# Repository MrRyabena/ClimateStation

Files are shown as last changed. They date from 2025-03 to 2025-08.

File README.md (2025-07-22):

ClimateStation_logo

---

[](https://github.com/MrRyabena/SmartHomeSystem)


---

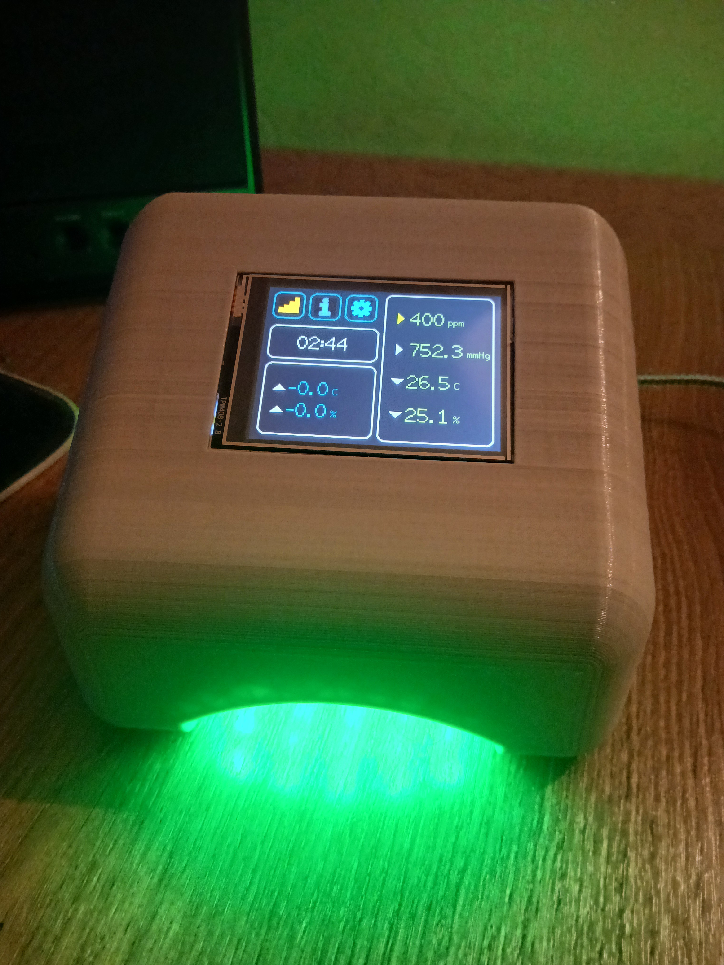
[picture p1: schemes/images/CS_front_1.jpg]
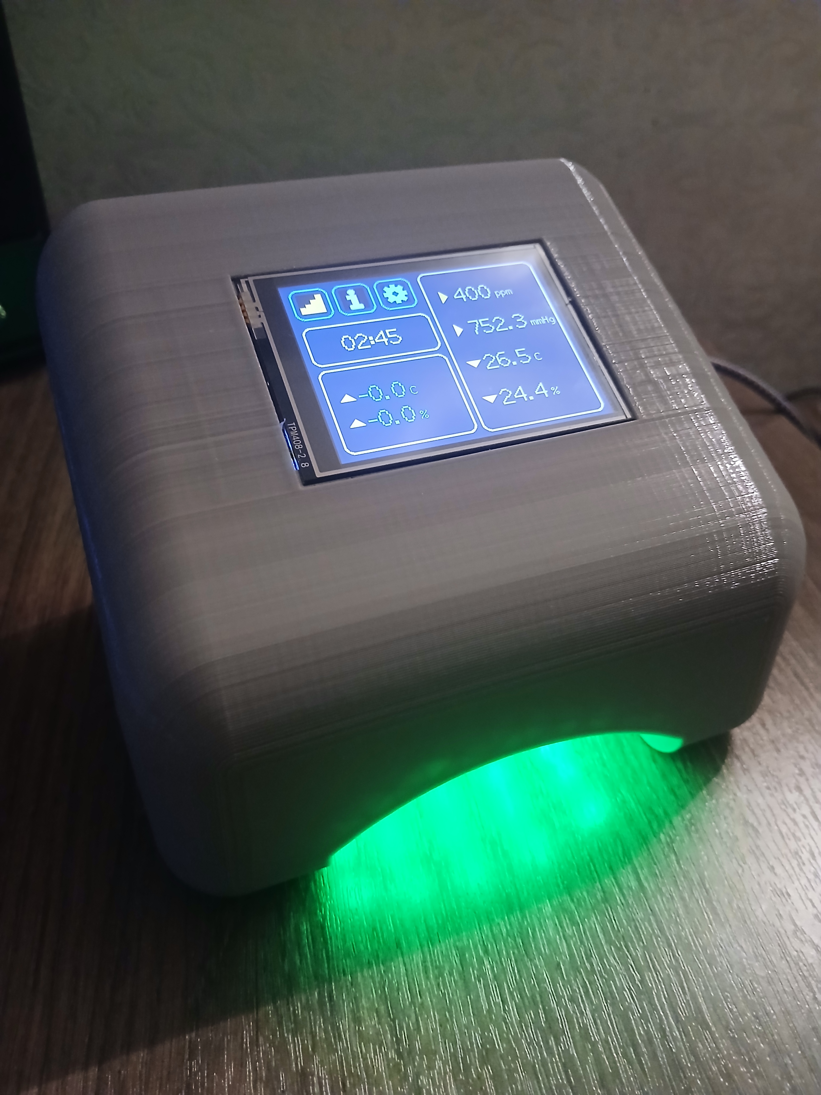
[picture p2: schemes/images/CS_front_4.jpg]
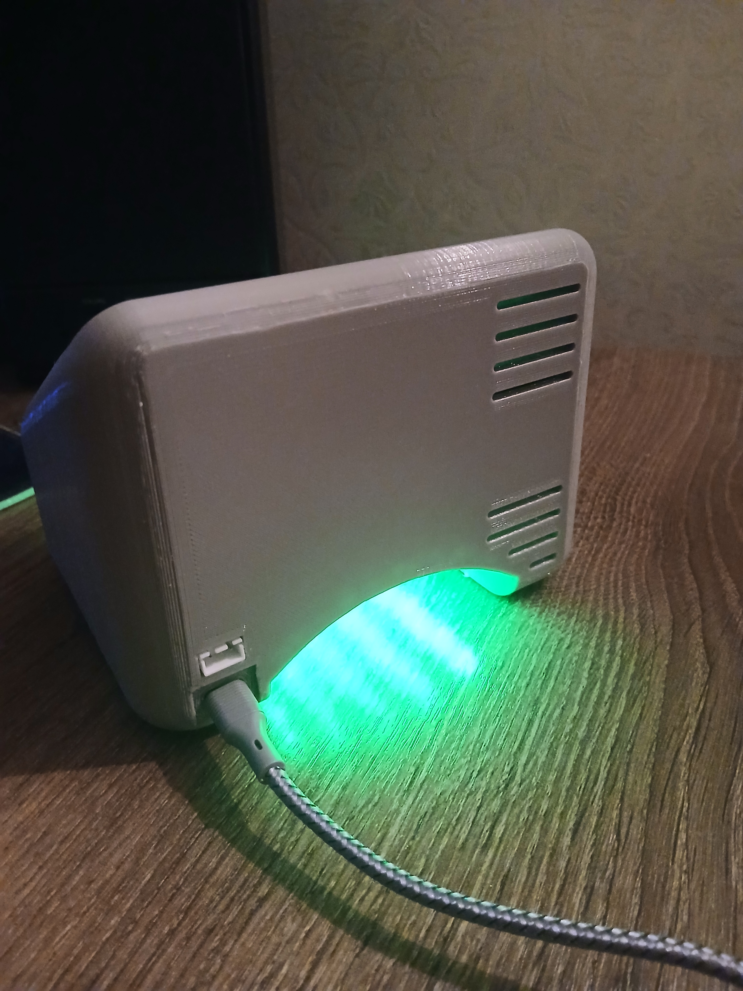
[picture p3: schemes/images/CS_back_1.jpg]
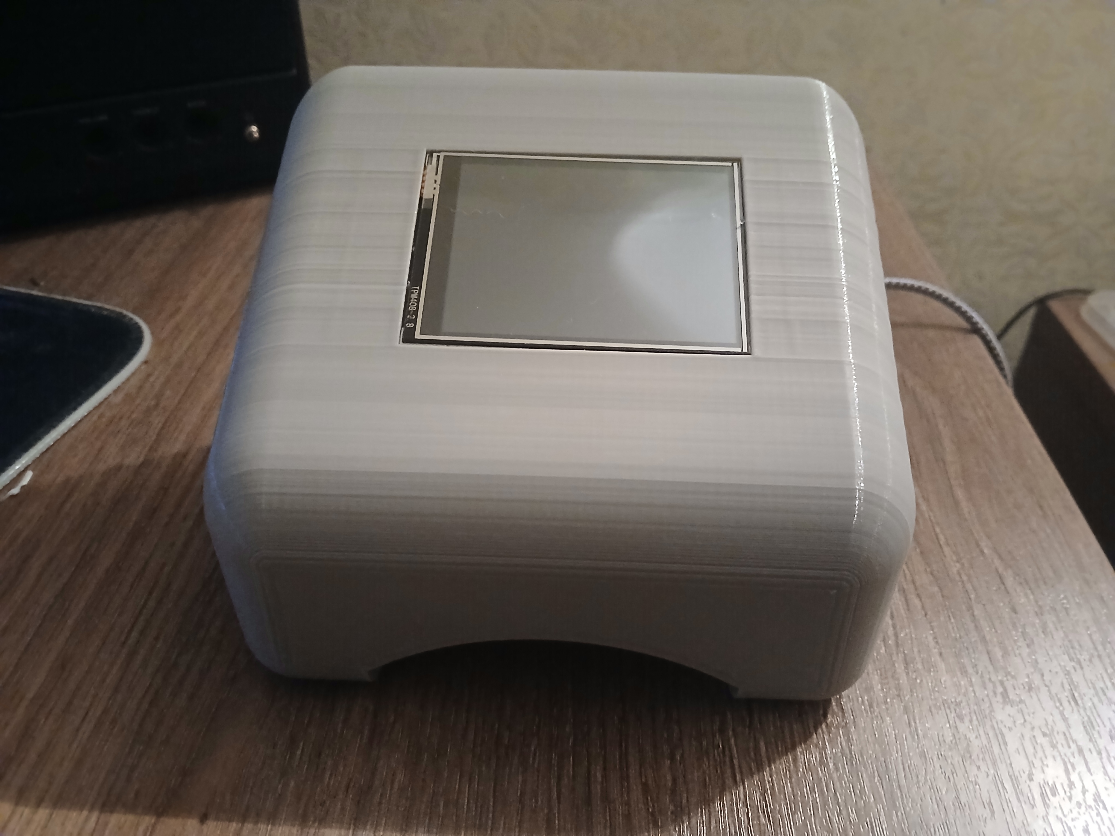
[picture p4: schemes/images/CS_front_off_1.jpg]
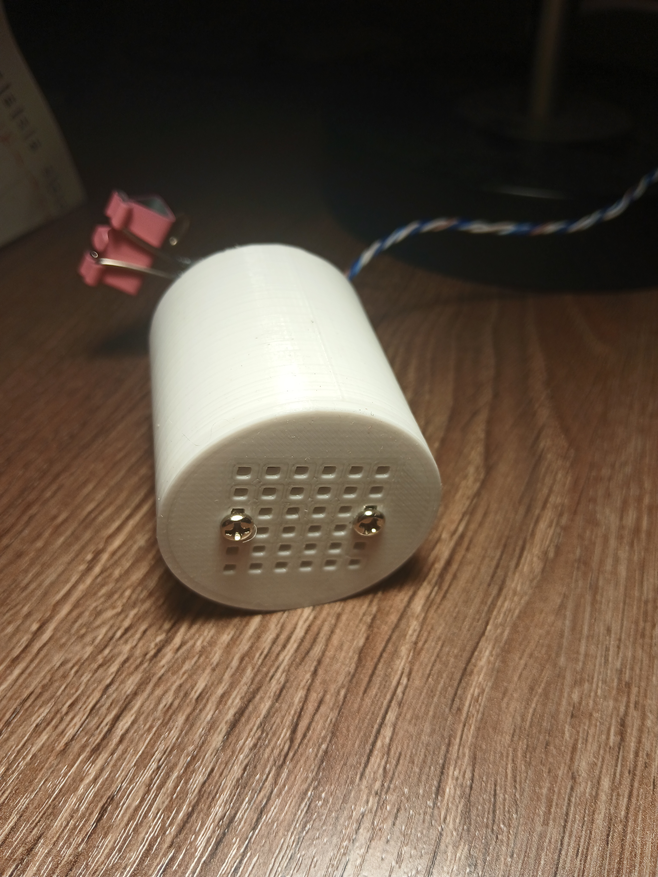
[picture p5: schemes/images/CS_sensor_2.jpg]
    

---

# ClimateStation by SmartHomeSystem

> [!NOTE]
> Проект является одним из устройств SmartHomeSystem. Внутри кода используется ядро и библиотека основного проекта — **_[SmartHomeSystem](https://github.com/MrRyabena/SmartHomeSystem)_**.</br>

## Versions

<details>
<summary>v1.0.0 — development beta-version.</summary>

</details>

<details>
<summary>v1.1.0 — <b><code>[current]</code></b>

</details>

## Components

[See list of components](/schemes/components/components_list.md).

## About

**_ClimateStation_** — метеостанция в специально разработанном для 3D-печати корпусе с сенсорным дисплеем. Собирает информацию с внутренних и внешних датчиков об атмосферном давлении, уровне CO2 (углекислого газа) в помещении, влажности и температуре воздуха. Станция умеет составлять прогноз погоды, подсказывать когда необходимо проветрить помещение и выводить показания с датчиков и графики их изменений. Сенсорный экран позволяет изменять настройки, переключать режимы работы и смотреть показания датчиков в реальном времени. Также устройство может обеспечивать обратную связь в системах климат-контроля **_SmartHomeSystem_**.

### Возможности

- Измерения:
  - Temperature in/out
  - Humidity in/out
  - Pressure
  - CO2 concentration
- Сенсорный дисплей:
  - Визуализация показателей в реальном времени
  - Расчёт и отображение тренда изменения величины (возрастает/убывает/не изменяется)
  - Переключение режимов и управление настройками
- Подсветка:
  - Визуальный контроль качества воздуха или изменения погодных условий
- Сбор и сохранение статистики
  - Вывод графиков за выбранные промежутки времени

## PCB
Для сборки устройства разработана печатная палата.





## Упаковка

Картонная [коробка](https://www.ozon.ru/product/kartonnaya-korobka-20h12h12-sm-korobka-dlya-upakovki-bizhuterii-i-yuvelirnyh-izdeliy-gofrokorob-384109582/) 200x12x12 mm. Обклеивается символикой из [logos/source/print.docx](logos/source/print.docx).

Внутрь вставляется картонная вставка (для создания разделов):

- Размеры вставки: 105x480
- Загибы: 195 + 115 + 55 + 115

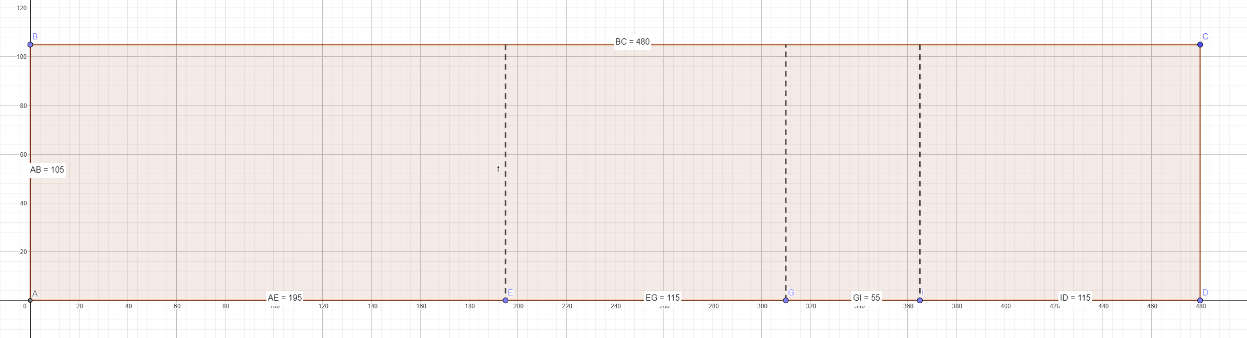
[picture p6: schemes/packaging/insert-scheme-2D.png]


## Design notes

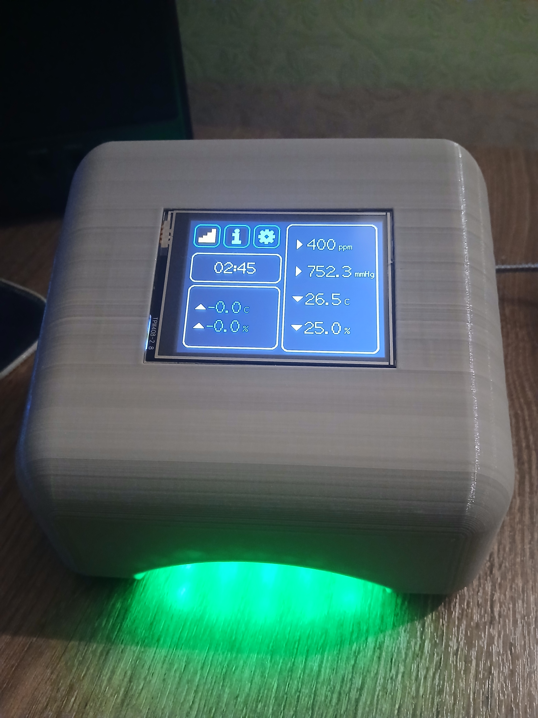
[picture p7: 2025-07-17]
schemes/images/CS_front_3.jpg

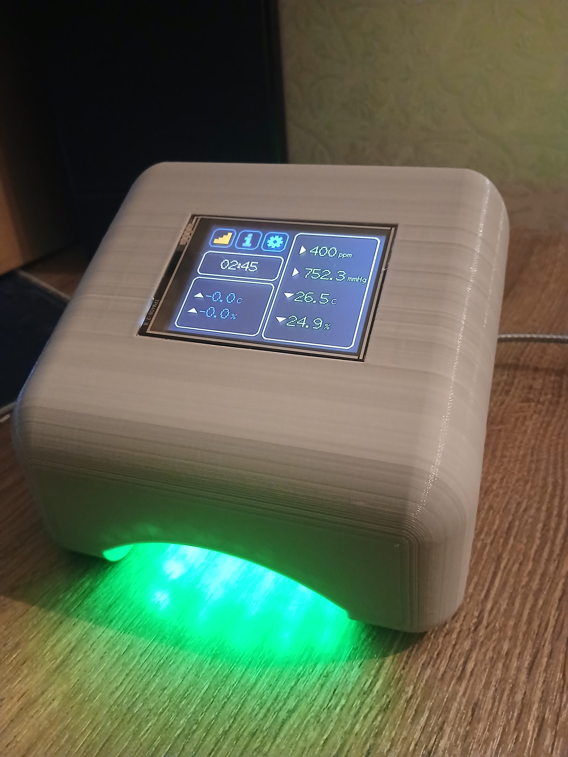
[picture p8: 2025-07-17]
schemes/images/CS_front_2.jpg

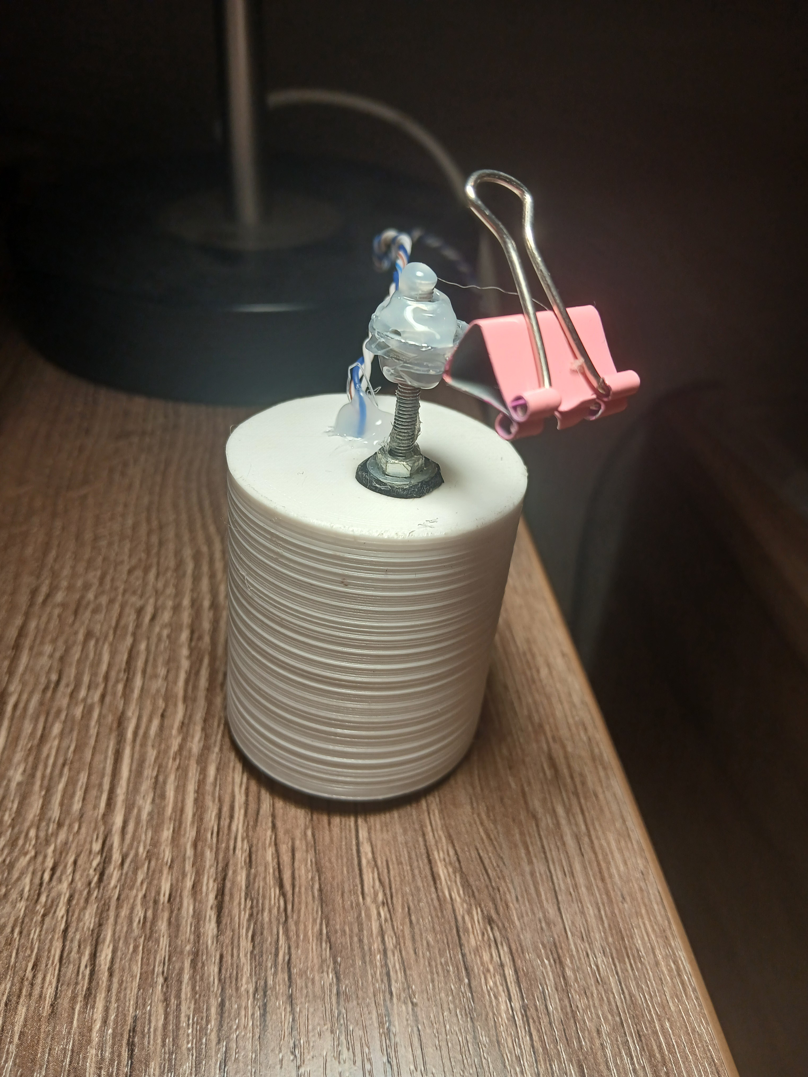
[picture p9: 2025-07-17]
schemes/images/CS_sensor_1.jpg

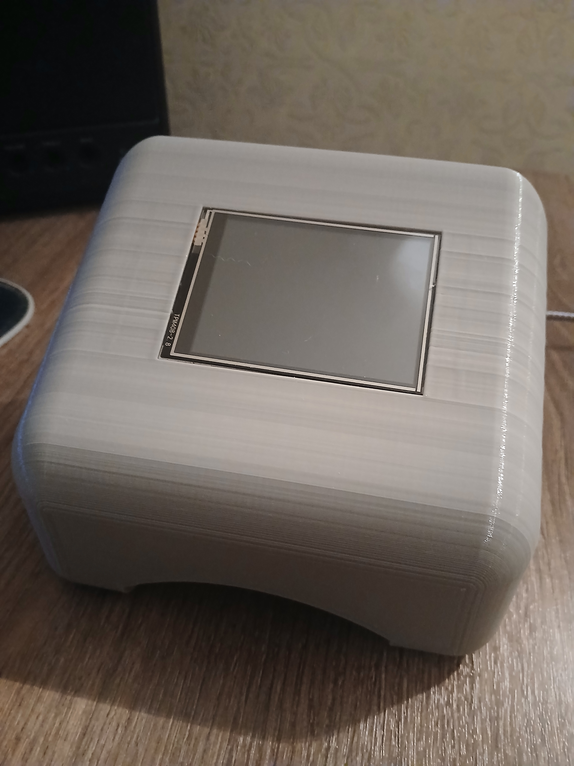
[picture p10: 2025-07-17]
schemes/images/CS_front_off_2.jpg

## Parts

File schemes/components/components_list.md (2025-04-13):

# Components

|№|component|type|datasheet|link|size|note|
|--|--|--|--|--|--|--|
|1.|MH-Z19B|sensor|[mh-z19b-co2-ver1_0.pdf](https://www.winsen-sensor.com/d/files/infrared-gas-sensor/mh-z19b-co2-ver1_0.pdf)|[Ozon](https://www.ozon.ru/search/?text=MH-Z19b&from_global=true)|33x20x9|CO2 gas sensor|
|2.|BME-280|sensor|[BME280.pdf](https://download.mikroe.com/documents/datasheets/)|[Aliexpress](https://aliexpress.ru/item/1005001827151118.html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)|16x12x2 + d3|Pressure, humidity and temperature sensor|
|3.|DTH-22|sensor|[DHT22.pdf](https://iarduino.ru/lib/DHT22.pdf?ysclid=m8ddeefn6p891731623)|[Aliexpress](https://aliexpress.ru/item/1005008495880246.html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)|34x16x8|Outdoor temperature and humidity sensor|
|4.|DS3231|clock|[ds3231.pdf](https://dinistor.ru/files/ds3231.pdf?ysclid=m8ddi9gb17518707617)|[Aliexpress](https://aliexpress.ru/item/1005007143842437.html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)|14x14x8|Real time clock module|
|5.|ESP8266/ESP32|microcontroller|—|—|—|Main controller|
|6.|3.3V dc-dc|power|—|[Aliexpress](https://aliexpress.ru/item/1005002921104409.html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)|17,5x12x5|Voltage converter|
|7.|TFT-display|display||[Aliexpress](https://aliexpress.ru/item/4000219159401.html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)|[TFT_2.8_scheme](TFT_2.8_scheme.png)|Touch display 2.8''|
|8.|usb type c|socket|—|[Aliexpress](https://aliexpress.ru/item/1005006047462864.html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)|12x15x4 + 16x12|Usp-socket for power supply|
|9.|Buzzer|buzzer|—|—|—|Buzzer|
|10.|ARGB led|LED|—|—|10x17 (1 segment)|Illumination of the lower part|
|11.|Outdoor sensor connector|connector|—|[Ozon](https://www.ozon.ru/product/razemy-3pin-shag-2-54mm-shteker-na-platu-gnezdo-na-provode-300mm-2-komplekta-1553830306/)|6x10x7 + (pins) 3(len)x2.5(step)x0.56(thin of each)|Connector for outdoor sensor (DHT22)|

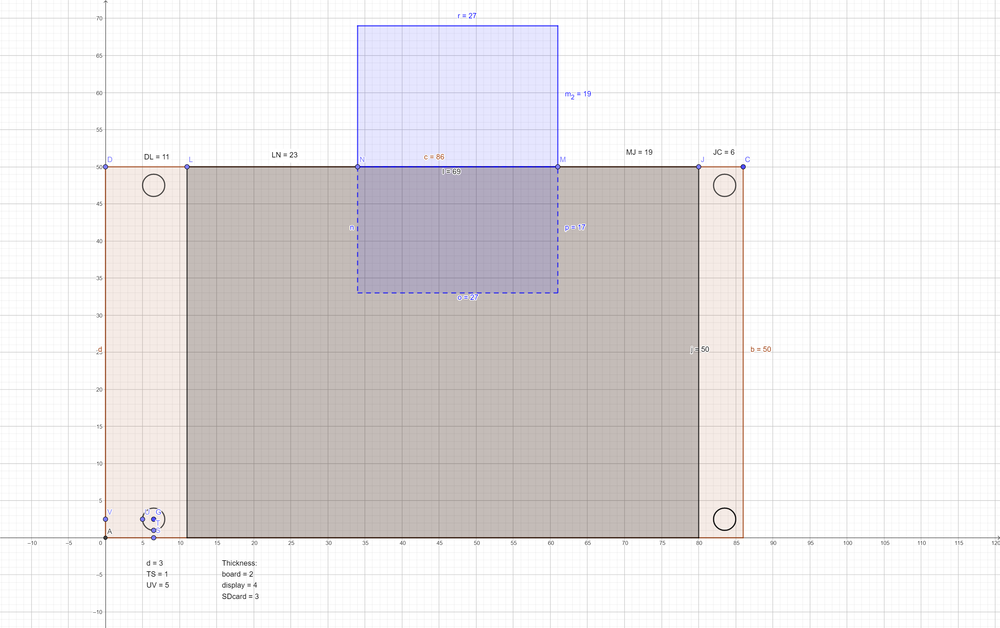
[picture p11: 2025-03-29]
schemes/components/TFT_2.8_scheme.png

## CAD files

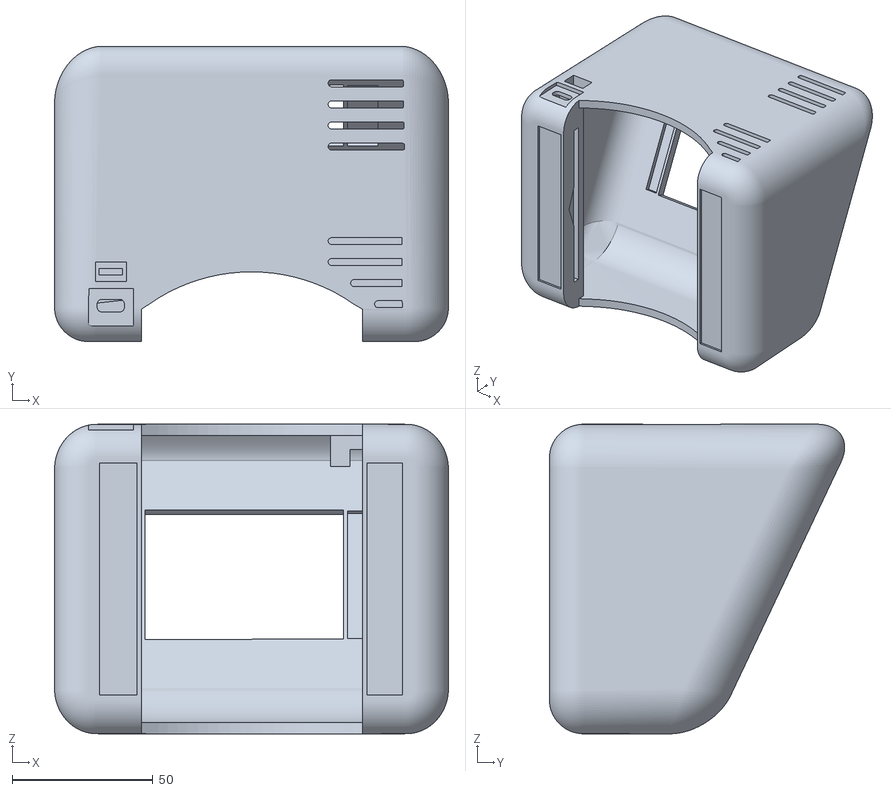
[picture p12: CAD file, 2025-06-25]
schemes/3D_models/base/base.obj
140.0 x 104.9 x 110.0

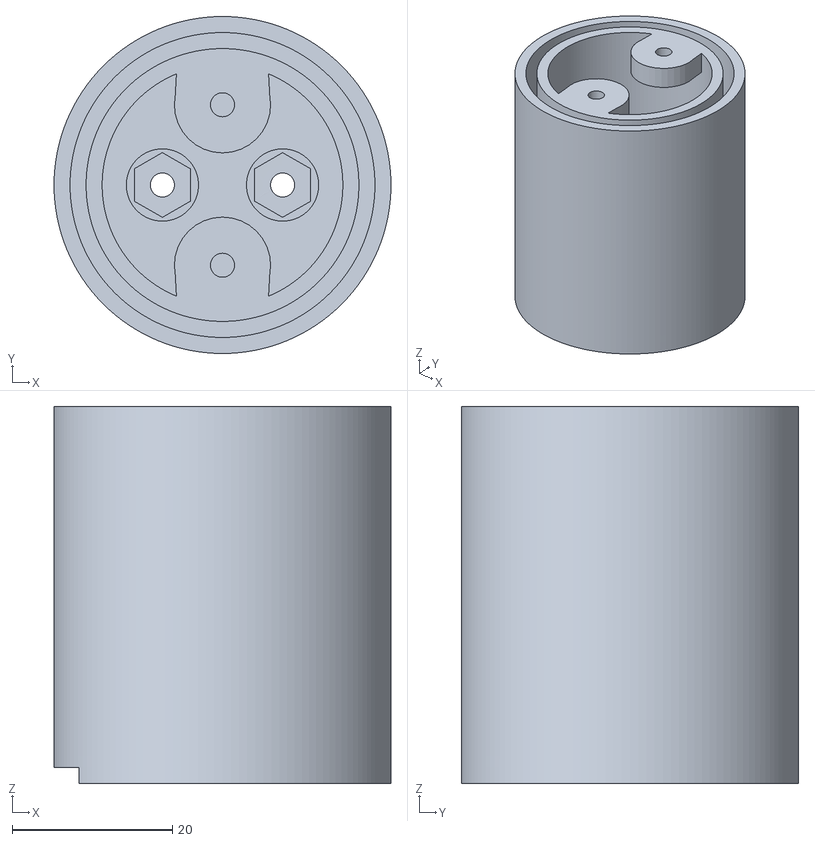
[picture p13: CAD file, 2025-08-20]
schemes/3D_models/outdoors/outdors.stl
42.0 x 42.0 x 47.0

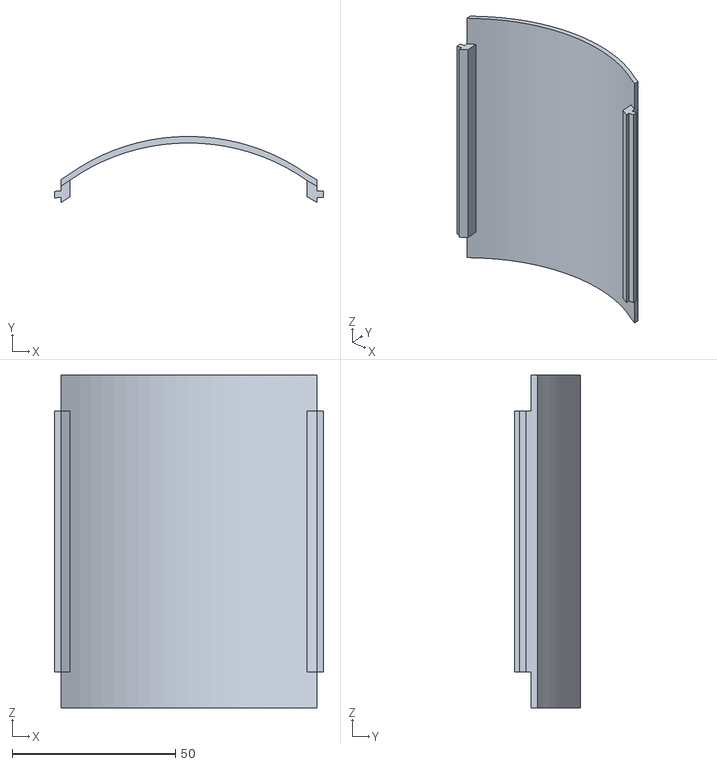
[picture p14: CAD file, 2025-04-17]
schemes/3D_models/base/cap.obj
82.5 x 20.3 x 102.0

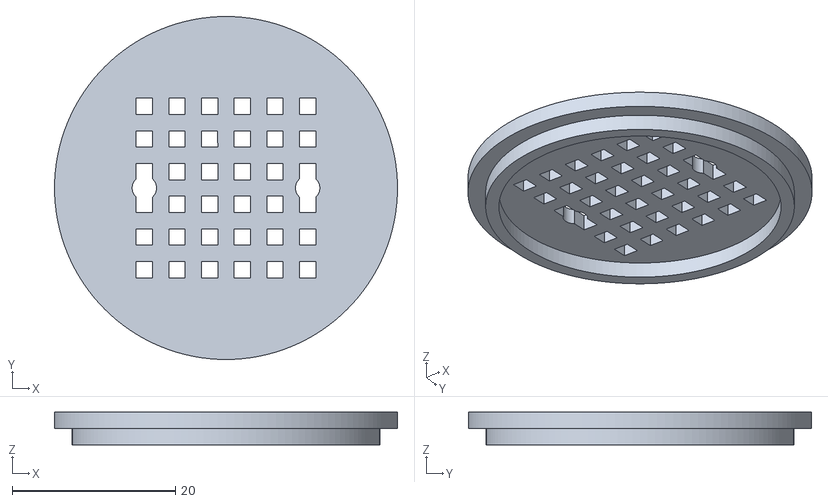
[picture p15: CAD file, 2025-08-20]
schemes/3D_models/outdoors/cap.stl
42.0 x 42.0 x 4.00

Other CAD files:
schemes/3D_models/base/cup.obj
schemes/3D_models/base/base.blend
schemes/3D_models/outdoors/cap.obj
schemes/3D_models/outdoors/outdors.blend
schemes/3D_models/outdoors/outdors.obj

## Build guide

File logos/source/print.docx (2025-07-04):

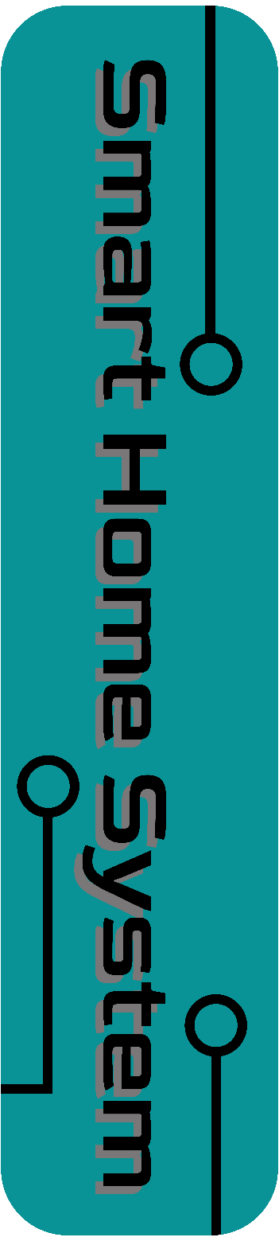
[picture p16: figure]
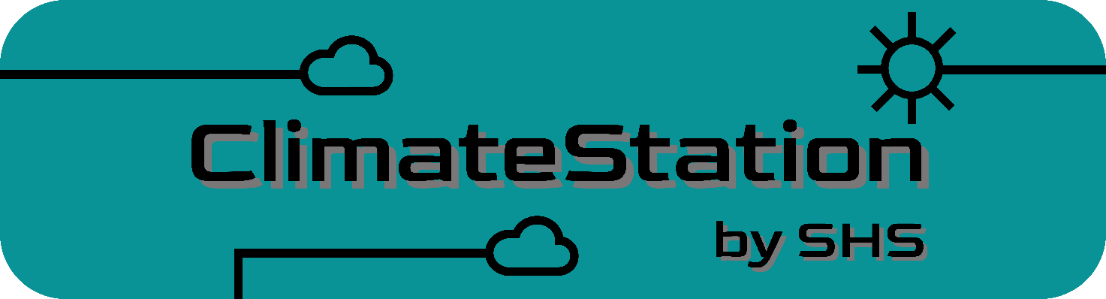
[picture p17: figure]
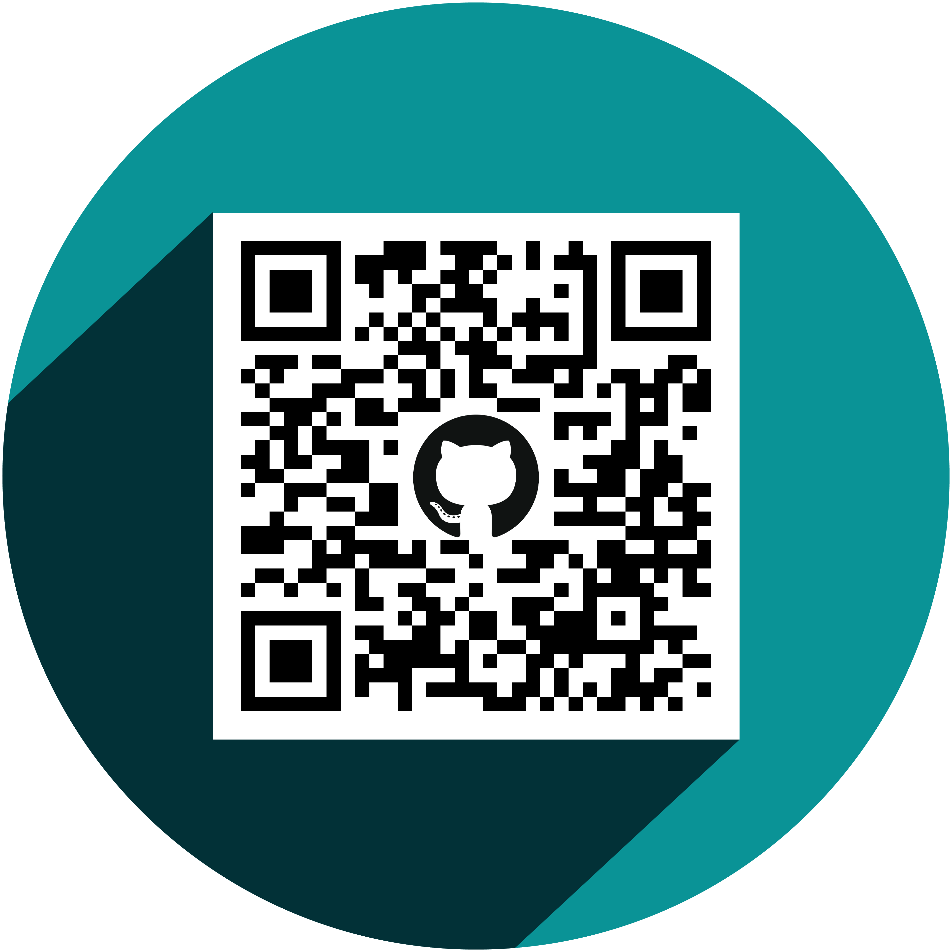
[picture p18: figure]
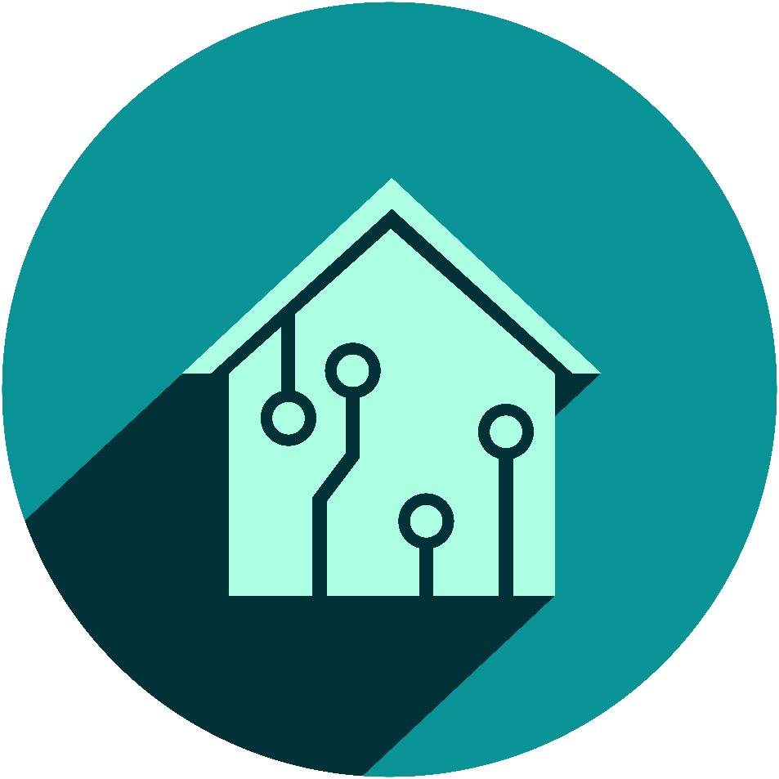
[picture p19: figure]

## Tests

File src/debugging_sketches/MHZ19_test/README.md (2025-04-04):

# MHZ19_test

Скеч для тестирования датчика MHZ19, а также сбора статистики. Показания обновляются каждую минуту и записываются файл, который можно получить из Telegram-бота. Файл состоит из записанных последовательно структур данных, без каких-либо разделителей и заголовочной информации.

```cpp
struct CSdata
{
    int32_t co2{};
    int32_t temp{};
};
```

Для расшифровки показаний написан скрипт [decoder](./src/decoder/decoder.py), который строит удобные для анализа графики:

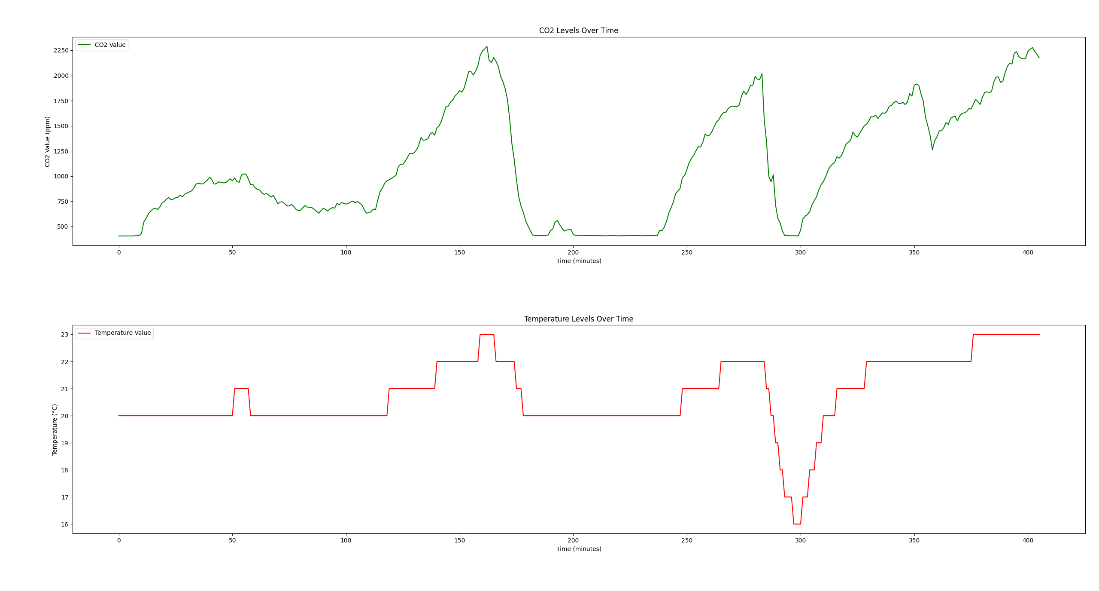
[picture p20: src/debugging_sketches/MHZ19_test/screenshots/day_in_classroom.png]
chart


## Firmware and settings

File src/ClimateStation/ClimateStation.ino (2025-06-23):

#include "settings.h"

#include <shs_settings_private.h>

#include <shs_ProgramTimer.h>

#include <memory>

#include "shs_ClimateStation.h"
#include "shs_ClimateStationVisualizer.h"
#include "shs_ClimateStationStorage.h"
#include "shs_ClimateStationConfig.h"
#include "ClimateStationGUIcore.h"
#include "shs_SDCard.h"
#include "UpdateWindow.h"

#include <SPI.h>
#include <TFT_eSPI.h>       // https://github.com/Bodmer/TFT_eSPI


#include <shs_ControlWiFi.h>
#include <shs_ProgramTimer.h>
#include <shs_utils.h>
#include <GyverNTP.h>

std::shared_ptr<TFT_eSPI> tft_ptr;

std::shared_ptr<shs::ClimateStationStorage> storage;
std::shared_ptr<shs::ClimateStation> climate_station;
std::shared_ptr<shs::ClimateStationVisualizer> climate_station_visualizer;


CRGB leds[LEDS_NUM]{};

#include <AutoOTA.h>
void checkUpdate();

void setup()
{
    // WiFi
    shs::ControlWiFi::connectWiFi();

    
    SPI.begin(SD_SCK, SD_MISO, SD_MOSI);
        
    tft_ptr = std::make_shared<TFT_eSPI>();

    // Storage

    storage = std::make_shared<shs::ClimateStationStorage>(SD_CS);
    storage->start();

    climate_station = std::make_shared<shs::ClimateStation>(storage);
    climate_station->start();
    


    FastLED.addLeds<WS2812B, LEDS_PIN, RGB>(leds, LEDS_NUM);  // GRB ordering is typical
    FastLED.setMaxPowerInMilliWatts(1500);

    climate_station_visualizer = std::make_shared<shs::ClimateStationVisualizer>(
    climate_station,
    storage,
    tft_ptr, storage->cs_config.TFT_LED_PIN, LEDS_NUM, LEDS_PIN
    );

    climate_station_visualizer->start();

    checkUpdate();

    climate_station_visualizer->enable();
}



void loop()
{
    storage->tick();
    climate_station->tick();
    climate_station_visualizer->tick();
}


void checkUpdate()
{
    shs::UpdateWindow window(tft_ptr, CLIMATE_STATION_ESP32_VERSION);
    window.start();
}

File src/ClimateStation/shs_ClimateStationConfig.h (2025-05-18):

#pragma once


#include <shs_types.h>
#include <shs_CRC.h>
#include <shs_version.h>

namespace shs
{
    struct ClimateStationConfig;
};


struct shs::ClimateStationConfig
{
    // ----------------------------------INFO-----------------------------------
    shs::version::Version config_version = "v1.1.0";

    // ---------------------------------SENSORS---------------------------------

    // MHZ19
    shs::t::shs_pin_t MHZ19_TX_PIN = 17;
    shs::t::shs_pin_t MHZ19_RX_PIN = 35;

    // DHT
    shs::t::shs_pin_t DHT_PIN = 1;

    // flags
    /*
       See enum class shs::ClimateStation::SensorsNumbers
       MHZ19_b = 0b1, BME280_b = 0b10, DHT_b = 0b100,
       DS3231_b = 0b1000, NTP_b = 0b10000, UPDATING_TIMEOUT_b = 0b100000,
    */
    uint8_t sensors_flags = 0b11111;

    // -------------------------------INDICATION--------------------------------

    // TFT
    shs::t::shs_pin_t TFT_LED_PIN = 19;

    uint32_t SLEEP_TIMEOUT = 120'000;      // 2 minutes

    uint32_t SAVE_TIMEOUT = 300'000;       // every 5 minutes

    // Backlight (LED)
    uint32_t LED_TIMEOUT = 120'000;        // 2 minutes
    uint16_t MIN_CO2 = 400u;
    uint16_t MAX_CO2 = 2200u;
    uint8_t  MIN_COLOR_H = 0;              // red
    uint8_t  MAX_COLOR_H = 90;             // green
    uint8_t  LED_BRIGHTNESS = 40;

};

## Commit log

2025-03-19 "hut" for outdoors sensor
    Door is for "hut" too. Door need to be printed not lying on flat
    [outdors.blend]
2025-03-22 load all files
    [outdors.blend]
2025-03-22 base file created
    [base.blend, outdors.blend]
2025-03-23 .obj files upload
    finally
    [base.blend, door.obj, outdors.obj]
2025-03-25 new scatch & modules placed
    [base.blend]
2025-03-28 complete first base sketch
    [base.blend, base.obj]
2025-03-28 bevel applied
    [base.blend, base.obj]
2025-03-29 Created a ClimateStation class, added sensors
2025-03-29 Added work with sensors. Added time control. Tested.
2025-04-03 Add the breadboard.
    [base.blend]
2025-04-06 fastening for all components inside model
    [base.blend, base.obj]
2025-04-07 The sizes have been adjusted.
    [base.blend]
2025-04-07 Improved debug, fixed bugs, tested.
    [ClimateStation.ino]
2025-04-13 Added outdoor sensor connector.
2025-04-13 Added thickness of connectors pins.
2025-04-13 new sketch created
    old sketch destroyed
    [base.blend]
2025-04-15 basic sketch created
    [base.blend]
2025-04-16 place for type c
    [base.blend, base.obj, cup.obj]
2025-04-17 The body has been completed.
    [base.blend, cap.obj]
2025-04-18 back wall repaired
    [base.blend, base.obj]
2025-04-18 edges rounded
    [base.blend, base.obj]
2025-04-19 The display of all sensors has been tested.
2025-04-20 Added function for printing debug.
2025-04-20 created place for stylus
    [base.blend]
2025-04-20 place for stylus delited
    [base.blend, base.obj]
2025-04-20 cilinder for BME
    [base.blend, base.obj]
2025-04-20 new outdoor sensor case
    [outdors.blend]
2025-04-20 Added frame for the text.
2025-04-23 tris for display
    [base.blend, base.obj]
2025-04-23 tri enlarge from 2 mm to 4 mm
    [base.blend, base.obj]
2025-04-24 places for screws on tris
    [base.blend, base.obj]
2025-04-25 obj updated
    [base.blend, base.obj]
2025-04-25 outdoors obj updated
    [base.blend, cap.obj, outdors.blend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]
2025-04-27 MHZ19_RX pin has been changed.
2025-04-29 bugs fixed
    [base.blend, base.obj]
2025-04-29 bug fixed
    [base.blend, base.obj]
2025-04-29 enlarged place for display
    [base.blend, base.obj]
2025-05-01 added plate to hold screen
    [base.blend, base.obj, plate.obj]
2025-05-03 Added the DHT22 sensor model.
    [outdors.blend]
2025-05-03 Made the cylinder shorter.
    [outdors.blend]
2025-05-03 Redesigned using std::shared_ptr. Added touch calibration. Added display sleep.
2025-05-03 Redesigned using std::shared_ptr. Added functions for saving and getting TFT calibration data.
2025-05-04 Added storage and icon for button.
2025-05-04 Added buttons and images.
2025-05-05 place for screws in outdoors module
    [outdors.blend, outdors.obj]
2025-05-06 screws for outdoors module
    [outdors.blend, outdors.obj]
2025-05-17 Added images for icons and buttons.
2025-05-17 Added work with an LED strip for backlight.
2025-05-17 Initialization via storage. New class for timers. Struct data moved to separete file.
2025-05-18 Added LED settings.
2025-05-19 Сlass has been created for the decrease and increase value interface.
2025-05-20 Switching on at high co2 levels. Improved settings interface.
2025-06-23 enlarge place for screen
    [base.blend, base.obj]
2025-06-25 right size for screen
    [base.blend, base.obj]
2025-06-25 plate removed
    [base.blend, base.obj, plate.obj]
2025-07-02 Created file for print stickers.
2025-07-05 A cardboard insert scheme has been created.
2025-07-16 Added PCB preview.
2025-08-20 stl added
    [cap.stl, outdors.blend, outdors.obj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]
